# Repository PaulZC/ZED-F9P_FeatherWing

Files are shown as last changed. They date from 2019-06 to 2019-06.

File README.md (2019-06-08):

# ZED-F9P_FeatherWing

An **untested** GNSS FeatherWing incorporating the dual-band (L1 + L2) [u-blox ZED-F9P](https://www.u-blox.com/en/product/zed-f9p-module)

If you need access to the ZED-F9P's USB port, check out the [ZED-F9P_FeatherWing_USB](https://github.com/PaulZC/ZED-F9P_FeatherWing_USB)

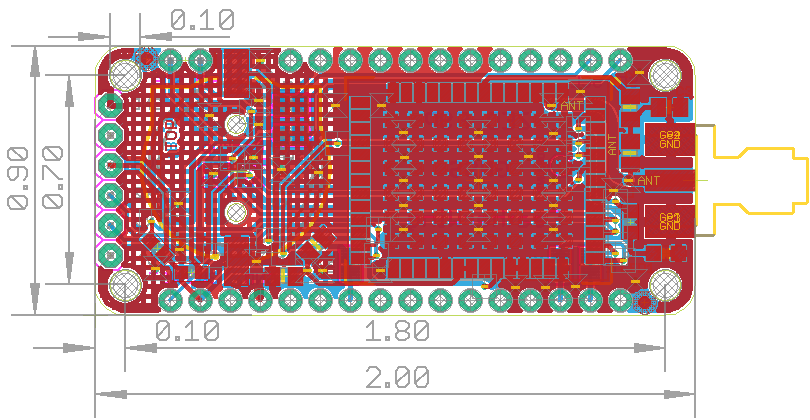
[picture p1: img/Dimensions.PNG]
Dimensions


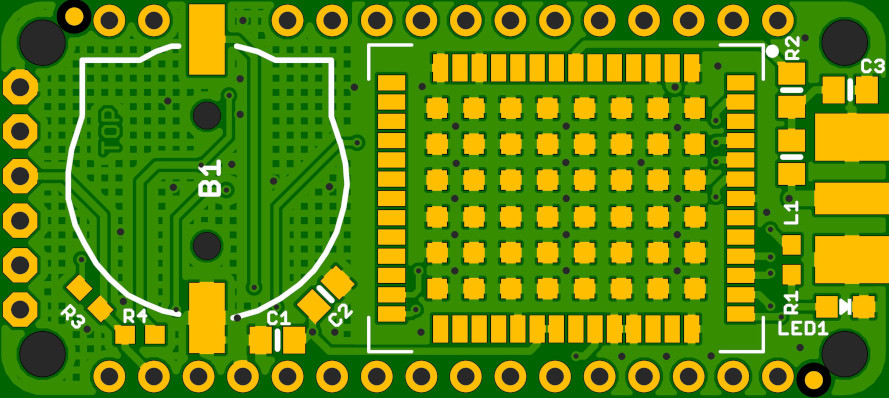
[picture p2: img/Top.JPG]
Top


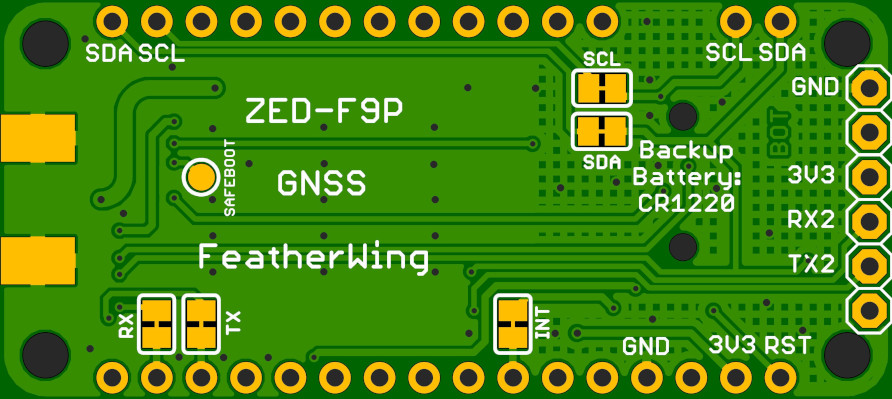
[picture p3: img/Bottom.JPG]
Bottom


Based extensively on the [Adafruit Ultimate GPS FeatherWing](https://www.adafruit.com/product/3133) and the
[SparkFun GPS-RTK2 Board](https://www.sparkfun.com/products/15136)

The Eagle files are available in the [Eagle folder](https://github.com/PaulZC/ZED-F9P_FeatherWing/tree/master/Eagle)

The schematic is available [here](https://github.com/PaulZC/ZED-F9P_FeatherWing/blob/master/img/Schematic.PNG)

The BOM is available [here](https://github.com/PaulZC/ZED-F9P_FeatherWing/blob/master/BOM.pdf)

PCB thickness should be 0.8mm: see the microstrip calculations on the [SparkFun schematic](https://cdn.sparkfun.com/assets/9/a/0/0/a/Qwiic_GPS-RTK2_-_ublox_ZED-F9P.pdf)

## Acknowledgements

This project would not have been possible without the open source designs kindly provided by both Adafruit and SparkFun. Their work is gratefully acknowledged.

Adafruit invests time and resources providing this open source design, please support Adafruit and open-source hardware by purchasing products from Adafruit!

## Licence

This project is distributed under a Creative Commons Attribution + Share-alike (BY-SA) licence.
Please refer to section 5 of the licence for the "Disclaimer of Warranties and Limitation of Liability".

Enjoy!

**_Paul_**

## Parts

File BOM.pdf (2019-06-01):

Name | X | Y | Angle | Package | Value | Farnell /
Element 14 Comments
FID1 | 4.35 | 21.81 | 0 | FIDUCIAL
FID2 | 46.51 | 1.06 | 0 | FIDUCIAL
B1 | 11.91 | 12.56 | 0 | CR1220 Holder | | 2064722 | e.g. Multicomp CH291-1220LF
C1 | 15.94 | 3.34 | 180 | 0805 | 10uF | 2496998 | e.g. Walsin 0805F106Z100CT
C2 | 18.68 | 5.95 | 45 | 0805 | 0.1uF | 2496944 | e.g. Walsin 0805B104K500CT
C3 | 48.58 | 17.62 | 0 | 0805 | 10nF | 2496939 | e.g. Walsin 0805B103K500CT
L1 | 45.24 | 13.78 | 270 | 0805 | 27nH | 2286463 | e.g. Coilcraft 0805HT-27NTGLB
LED1 | 48.3 | 5.24 | 270 | 2.0x1.25 | RED | 2322077 | e.g. Wurth Electronik 150080RS75000
R1 | 45.24 | 7.93 | 270 | 0603 | 1K | 2447272 | e.g. Multicomp MCWR06X1001FTL
R2 | 45.24 | 17.61 | 90 | 0805 | 10 ohm | 9332421 | e.g. Multicomp MC01W0805110R
R3 | 5.24 | 5.71 | 135 | 0603 | 1K | 2447272 | e.g. Multicomp MCWR06X1001FTL
R4 | 8.1 | 3.65 | 0 | 0603 | 1K | 2447272 | e.g. Multicomp MCWR06X1001FTL
U1 | 32.38 | 11.43 | 180 | ZED-F9P | ZED-F9P | https://www.u-blox.com/en/product/zed-f9p-module
X1 | 48.68 | 11.43 | 180 | SMA Jack | | 1019328 | e.g. Johnson 142-0711-821 1019328

Extras

B1 | | | | CR1220 | 3V Lithium | 2065165 | e.g. Multicomp CR1220

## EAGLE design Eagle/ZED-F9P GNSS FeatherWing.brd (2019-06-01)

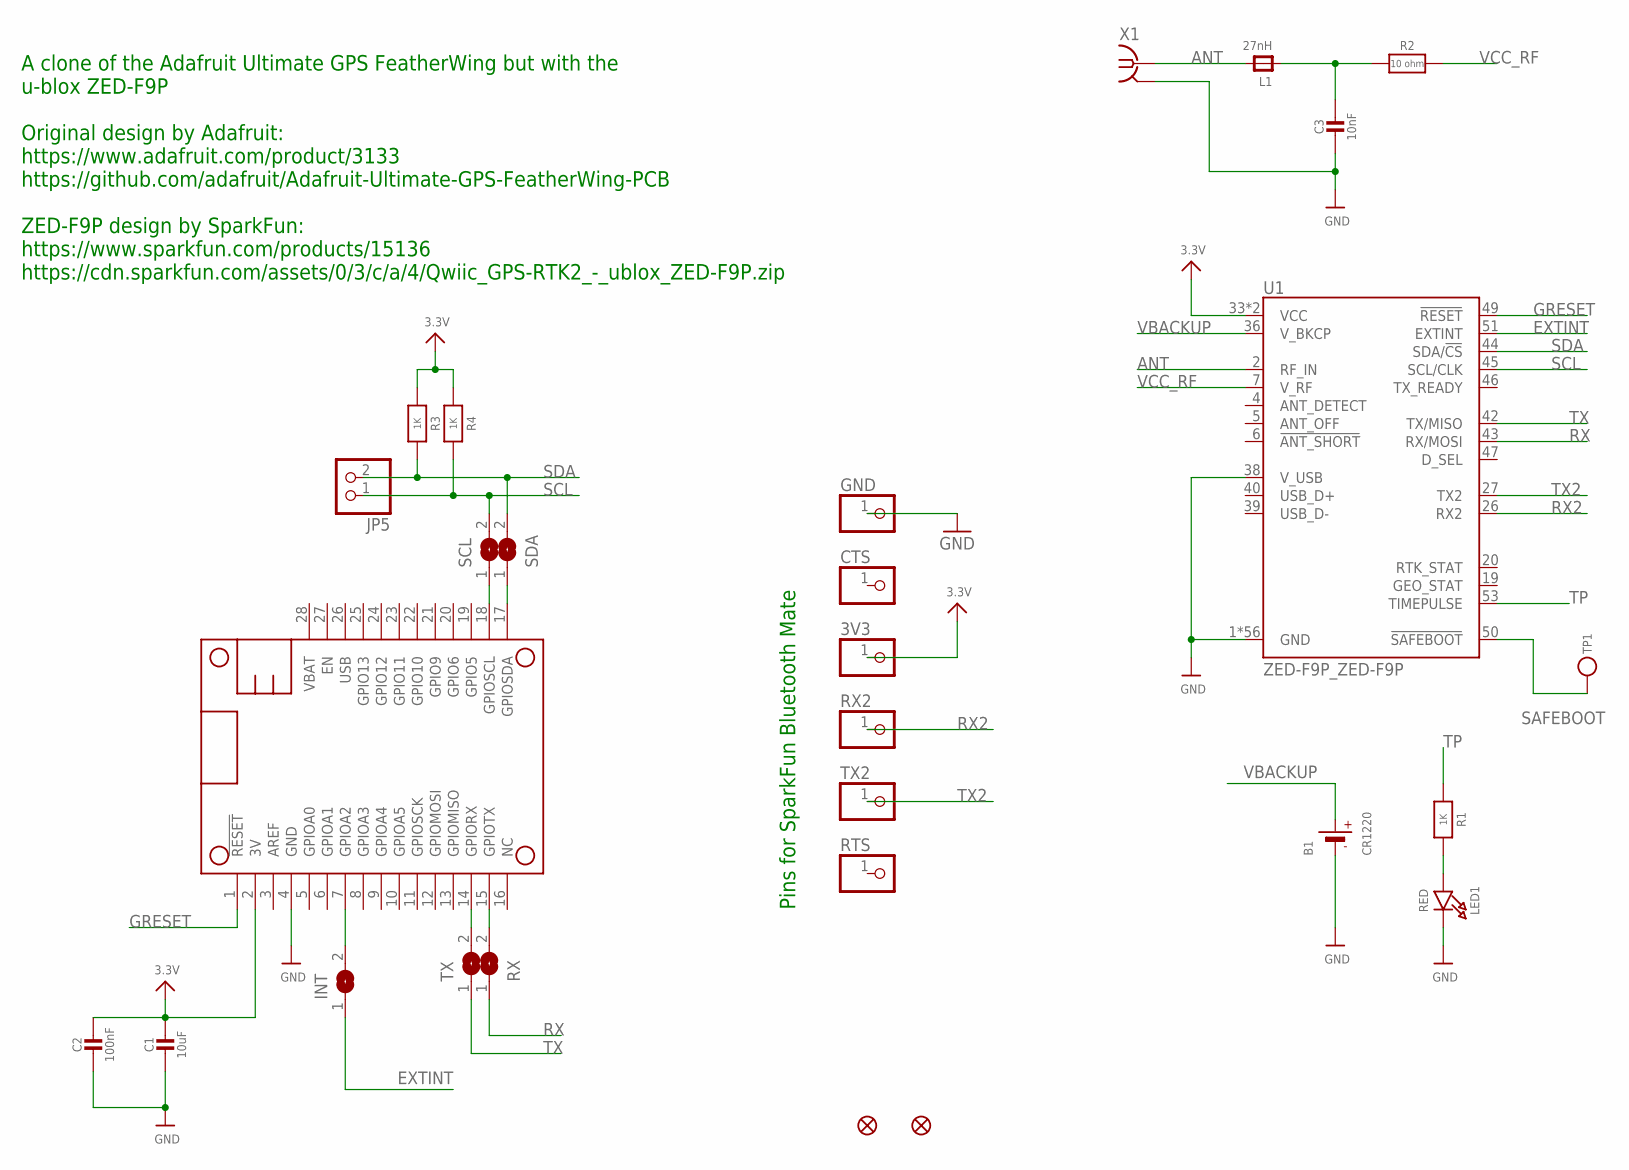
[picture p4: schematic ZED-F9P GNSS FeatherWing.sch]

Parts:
3V3: PINHD-1X1; 1X01
B1: CR1220; CR1220-2
C1: 10uF; 0805-NO
C2: 100nF; 0805-NO
C3: 10nF; 0805-NO
CTS: PINHD-1X1; 1X01
FID1, FID2: FIDUCIAL""; FIDUCIAL_1MM
GND: PINHD-1X1; 1X01
INT: SOLDERJUMPERCLOSED; SOLDERJUMPER_CLOSEDWIRE
JP5: HEADER-1X2ROUND; 1X02_ROUND
L1: 27nH; 0805-NO
LED1: RED; CHIPLED_0805_NOOUTLINE
MS1: MICROBUILDER_FEATHERWINGMICROBUILDER_FEATHERWING_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; MICROBUILDER_FEATHERWING_HOLES
R1, R3, R4: 1K; 0603-NO
R2: 10 ohm; 0805-NO
RTS: PINHD-1X1; 1X01
RX: SOLDERJUMPERCLOSED; SOLDERJUMPER_CLOSEDWIRE
RX2: PINHD-1X1; 1X01
SCL: SOLDERJUMPERCLOSED; SOLDERJUMPER_CLOSEDWIRE
SDA: SOLDERJUMPERCLOSED; SOLDERJUMPER_CLOSEDWIRE
TP1: TESTPOINTROUND1.5MM; TESTPOINT_ROUND_1.5MM
TX: SOLDERJUMPERCLOSED; SOLDERJUMPER_CLOSEDWIRE
TX2: PINHD-1X1; 1X01
U1: ZED-F9P_ZED-F9P
X1: SMA-142-0711-821/826; J502-ND-142-0711-821/826

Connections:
3.3V: 3V3.1, C1.1, C2.1, MS1.2 (3V), R3.1, R4.1, U1.33 (VCC), U1.34 (VCC)
ANT: L1.2, U1.2 (RF_IN), X1.1
EXTINT: INT.1, U1.51 (EXTINT)
GND: B1.-, C1.2, C2.2, C3.2, GND.1, LED1.C, MS1.4 (GND), U1.1 (GND), U1.3 (GND), U1.12 (GND), U1.14 (GND), U1.32 (GND), U1.37 (GND), U1.38 (V_USB), U1.41 (GND), U1.48 (GND), U1.55 (GND), U1.56 (GND), U1.57 (GND), U1.58 (GND), U1.59 (GND), U1.60 (GND), U1.61 (GND), U1.62 (GND), U1.63 (GND), U1.64 (GND), U1.65 (GND), U1.66 (GND), U1.67 (GND), U1.68 (GND), U1.69 (GND), U1.70 (GND), U1.71 (GND), U1.72 (GND), U1.73 (GND), U1.74 (GND), U1.75 (GND), U1.76 (GND), U1.77 (GND), U1.78 (GND), U1.79 (GND), U1.80 (GND), U1.81 (GND), U1.82 (GND), U1.83 (GND), U1.84 (GND), U1.85 (GND), U1.86 (GND), U1.87 (GND), U1.88 (GND), U1.89 (GND), U1.90 (GND), U1.91 (GND), U1.92 (GND), U1.93 (GND), U1.94 (GND), U1.95 (GND), U1.96 (GND), U1.97 (GND), U1.98 (GND), U1.99 (GND), U1.100 (GND), U1.101 (GND), U1.102 (GND), X1.G@1 (2), X1.G@2 (2), X1.G@3 (2), X1.G@4 (2)
GRESET: MS1.1 (!RESET), U1.49 (!RESET!)
unnamed: MS1.18 (GPIOSCL), SCL.1
unnamed: LED1.A, R1.2
unnamed: MS1.17 (GPIOSDA), SDA.1
unnamed: C3.1, L1.1, R2.1
unnamed: MS1.14 (GPIORX), TX.2
unnamed: MS1.15 (GPIOTX), RX.2
unnamed: INT.2, MS1.7 (GPIOA2)
RX: RX.1, U1.43 (RX/MOSI)
RX2: RX2.1, U1.26 (RX2)
SAFEBOOT: TP1.P$1, U1.50 (!SAFEBOOT!)
SCL: JP5.1, R4.2, SCL.2, U1.45 (SCL/CLK)
SDA: JP5.2, R3.2, SDA.2, U1.44 (SDA/!CS!)
TP: R1.1, U1.53 (TIMEPULSE)
TX: TX.1, U1.42 (TX/MISO)
TX2: TX2.1, U1.27 (TX2)
VBACKUP: B1.+, U1.36 (V_BKCP)
VCC_RF: R2.2, U1.7 (V_RF)

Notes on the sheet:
A clone of the Adafruit Ultimate GPS FeatherWing but with the u-blox ZED-F9P Original design by Adafruit: https://www.adafruit.com/product/3133 https://github.com/adafruit/Adafruit-Ultimate-GPS-FeatherWing-PCB ZED-F9P design by SparkFun: https://www.sparkfun.com/products/15136 https://cdn.sparkfun.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
Pins for SparkFun Bluetooth Mate

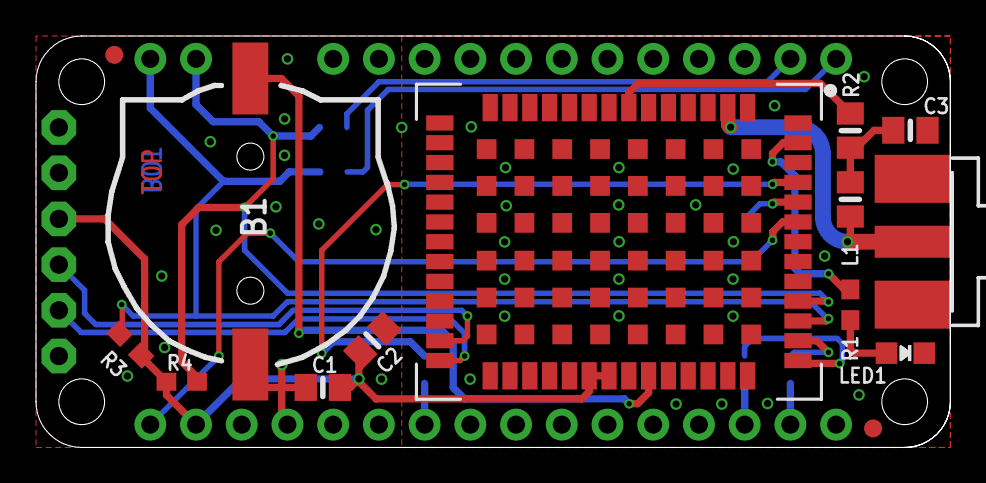
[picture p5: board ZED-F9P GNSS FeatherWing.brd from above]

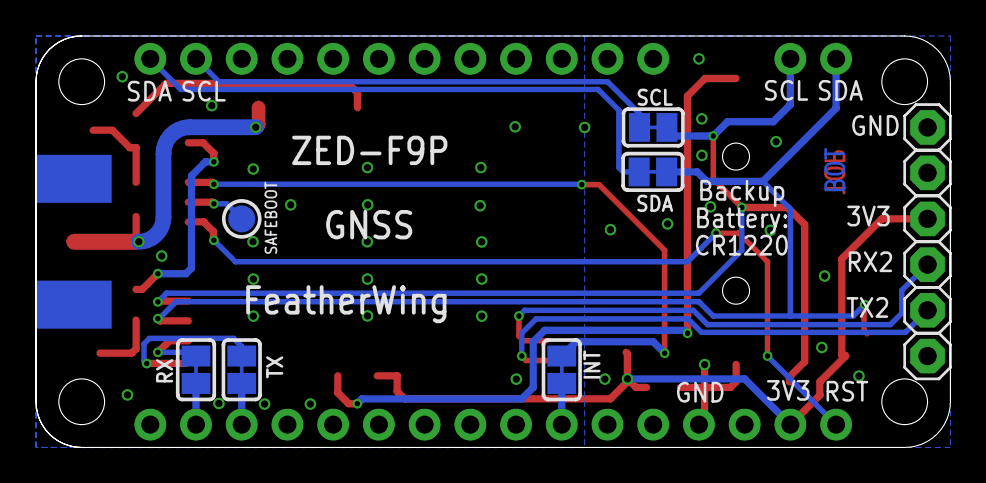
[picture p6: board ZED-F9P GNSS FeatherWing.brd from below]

Board: 2 copper layers, 50.8 x 22.9 mm, 28 parts (12 on the bottom side), 22 nets.
